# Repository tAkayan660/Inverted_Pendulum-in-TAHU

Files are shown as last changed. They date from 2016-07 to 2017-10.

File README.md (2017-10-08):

# Inverted_Pendulum-in-TAHU

## 機能
1. ロボット本体を倒立振子する
2. マイコンはArduino Megaを使用
3. 姿勢制御にIMU（MPU-6050）を使用



## 動画

倒立        https://youtu.be/ehn2ii576s0?t=45s

重心下げ    https://youtu.be/hFfJ6d6ZRYU

再生リスト　https://www.youtube.com/playlist?list=PLqcSOQa__YqBw24QBU1EO53jK8HO_nGts

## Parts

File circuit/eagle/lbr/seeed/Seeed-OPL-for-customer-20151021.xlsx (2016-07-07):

OPL list
Seeed SKU | MPN | Description | Category | Package | Manufacturer | Datasheet | Price（$）/pcs | Pieces/set | Solder points Qty | Assem.Cost/pcs（$） | Image URL | Distributor-URL
306010055 | FC-135 | SMD Crystal ABS07-32.768KHZ-7pF-20ppm-70K; | Crystal Oscillator | 2P-L3.2*W1.5mm | Xinhunjing | http://www.seeedstudio.com/wiki/images/7/78/306010055.pdf | 0.350 | 5 | 4 | 0.40 |  | http://www.seeedstudio.com/depot/OPLopen-parts-library-catalog-c-136_138/#306010055
306010005 | 49S | DIP Crystal 25MHz-20pF-20ppm;HC49US | Crystal Oscillator | HC49US | Xinhunjing | http://www.seeedstudio.com/wiki/images/5/5e/306010005.pdf | 0.150 | 10 | 2 | 0.20 |  | http://www.seeedstudio.com/depot/OPLopen-parts-library-catalog-c-136_138/#306010005
306010037 | 49S/18PF | DIP Crystal 16MHz-18pF-30ppm-50R; | Crystal Oscillator | HC49/US | Xinhunjing | http://www.seeedstudio.com/wiki/images/5/57/306010037.pdf | 0.150 | 10 | 2 | 0.20 |  | http://www.seeedstudio.com/depot/OPLopen-parts-library-catalog-c-136_138/#306010037
306010054 | X053201602002 | SMD 16MHz-8pF-20ppm-40R | Crystal Oscillator | 2P-SMD-5.0X3.2 | JINGPENGYUAN | http://www.seeedstudio.com/wiki/images/9/9f/0500290P1.pdf | 0.350 | 5 | 2 | 0.20 |  | http://www.seeedstudio.com/depot/OPLopen-parts-library-catalog-c-136_138/#0500290P1
306010047 | 5032/2P | SMD Crystal 12Mhz-20pF-20ppm-40R; | Crystal Oscillator | 2P-L5.0*W3.2mm | Xinhunjing | http://www.seeedstudio.com/wiki/images/c/c7/306010047.pdf | 0.450 | 5 | 2 | 0.20 |  | http://www.seeedstudio.com/depot/OPLopen-parts-library-catalog-c-136_138/#306010047
306010004 | 5032/4P | SMD Crystal 8MHz-20pF-20ppm; | Crystal Oscillator | 2P-L5.0*W3.2mm | Xinhunjing | http://www.seeedstudio.com/wiki/images/9/91/306010004.pdf | 0.450 | 5 | 2 | 0.20 |  | http://www.seeedstudio.com/depot/OPLopen-parts-library-catalog-c-136_138/#306010004
306010033 | 49S8M | DIP Crystal 8MHz-20pF-20ppm-60R; | Crystal Oscillator | HC49S | Xinhunjing | http://www.seeedstudio.com/wiki/images/c/ca/306010033.pdf | 0.150 | 10 | 2 | 0.20 |  | http://www.seeedstudio.com/depot/OPLopen-parts-library-catalog-c-136_138/#306010033
305030028 | 2N7002,215 | SMD MOSFET N-CH 60V-300mA Logic Level FET; | Transistor | SOT-23 | NXP | http://www.seeedstudio.com/wiki/images/c/c6/305030028.pdf | 0.050 | 30 | 3 | 0.30 |  | http://www.seeedstudio.com/depot/OPLopen-parts-library-catalog-c-136_138/#305030028
305030015 | CJ2302 | SMD MOSFET N-CH 20V 2.1A | Transistor | SOT23 | JCET | http://www.seeedstudio.com/wiki/images/e/e7/0440200P1.pdf | 0.100 | 10 | 3 | 0.30 |  | http://www.seeedstudio.com/depot/OPLopen-parts-library-catalog-c-136_138/#0440200P1
305030018 | Si2343CDS | SMD MOSFET P-CH 30V-5.9A | Transistor | SOT-23 | Vishay Siliconix |  | 0.700 | 5 | 3 | 0.30 |  | http://www.seeedstudio.com/depot/OPLopen-parts-library-catalog-c-136_138/#305030018
305030014 | CJ2305 | SMD MOSFET P-CH -8V -4.1A | Transistor | SOT-23 | JCET | http://www.seeedstudio.com/wiki/images/a/ac/0440210P1.pdf | 0.100 | 10 | 3 | 0.30 |  | http://www.seeedstudio.com/depot/OPLopen-parts-library-catalog-c-136_138/#0440210P1
305010018 | S9013 | SMD Transistors NPN 25V-500mA | Transistor | SOT-23 | JCET | http://www.seeedstudio.com/wiki/images/6/67/0400000P1.pdf | 0.040 | 50 | 3 | 0.30 |  | http://www.seeedstudio.com/depot/OPLopen-parts-library-catalog-c-136_138/#0400000P1
305020006 | S8550 | SMD Transistors PNP 25V-500mA | Transistor | SOT-23 |  | http://www.seeedstudio.com/wiki/images/e/e5/0410030P1.pdf | 0.040 | 50 | 3 | 0.30 |  | http://www.seeedstudio.com/depot/OPLopen-parts-library-catalog-c-136_138/#0410030P1
305010017 | S8050 | SMD Transistors NPN 25V-500mW; | Transistor | SOT-23 | JCET | http://www.seeedstudio.com/wiki/images/b/ba/305010017.pdf | 0.040 | 50 | 3 | 0.30 |  | http://www.seeedstudio.com/depot/OPLopen-parts-library-catalog-c-136_138/#305010017
305010022 | S9014J6 | SMD Transistor NPN 50V-100mA; | Transistor | SOT-23 | Changjiang | http://www.seeedstudio.com/wiki/images/2/2c/305010022.pdf | 0.050 | 30 | 3 | 0.30 |  | http://www.seeedstudio.com/depot/OPLopen-parts-library-catalog-c-136_138/#305010022
312010004 | KS-12065D03YA | DIP Buzzer 3V,30mA, 2700±300Hz | Audio product | 2P-7.6-D12*H6.5mm | Guangjixing | http://www.seeedstudio.com/wiki/images/c/cb/312020003.pdf | 0.500 | 5 | 2 | 0.20 |  | http://www.seeedstudio.com/depot/OPLopen-parts-library-catalog-c-136_138/#312010004
302020027 | TAJD477M006RNJ | SMD CAP Tantalum 470uF-6.3V;D | Capacitor | AVX-D | AVX |  | 0.500 | 5 | 2 | 0.20 |  | http://www.seeedstudio.com/depot/OPLopen-parts-library-catalog-c-136_138/#302020027
302030031 |  | DIP CAP Aluminum 100uF-16V | Capacitor | Radial-D5.0*H7.0mm | JWCO | http://www.seeedstudio.com/wiki/images/1/14/302030031.pdf | 0.030 | 50 | 2 | 0.20 |  | http://www.seeedstudio.com/depot/OPLopen-parts-library-catalog-c-136_138/#302030031
302020025 | TAJC107K010RNJ | SMD CAP Tantalum 100uF-10V 10% | Capacitor | AVX-C | AVX | http://www.seeedstudio.com/wiki/images/a/ae/0130170P1.pdf | 0.200 | 10 | 2 | 0.20 |  | http://www.seeedstudio.com/depot/OPLopen-parts-library-catalog-c-136_138/#0130170P1
302020022 | TAJC476K016RNJ | SMD CAP Tantalum 47uF-16V | Capacitor | AVX-C | AVX | http://www.seeedstudio.com/wiki/images/c/c7/302020022.pdf | 0.200 | 10 | 2 | 0.20 |  | http://www.seeedstudio.com/depot/OPLopen-parts-library-catalog-c-136_138/#302020022
302020020 | TAJB476K010RNJ | SMD CAP Tantalum 47uF-10V 10% | Capacitor | AVX-B | AVX | http://www.seeedstudio.com/wiki/images/f/fb/0130180P1.pdf | 0.200 | 10 | 2 | 0.20 |  | http://www.seeedstudio.com/depot/OPLopen-parts-library-catalog-c-136_138/#0130180P1
302020005 | TAJC476K006RNJ | SMD CAP Tantalum 47uF-6.3V | Capacitor | AVX-A | AVX |  | 0.150 | 20 | 2 | 0.20 |  | http://www.seeedstudio.com/depot/OPLopen-parts-library-catalog-c-136_138/#302020005
302020026 | TAJC226K025RNJ | SMD CAP Tantalum 22uF-25V 10% 2312 | Capacitor | AVX-C | AVX | http://www.seeedstudio.com/wiki/images/f/fd/0130360P1.pdf | 0.370 | 10 | 2 | 0.20 |  | http://www.seeedstudio.com/depot/OPLopen-parts-library-catalog-c-136_138/#0130360P1
302020021 | TAJB226K010RNJ | SMD CAP Tantalum 22uF-10V 10% | Capacitor | AVX-B | AVX | http://www.seeedstudio.com/wiki/images/8/82/0130240P1.pdf | 0.130 | 20 | 2 | 0.20 |  | http://www.seeedstudio.com/depot/OPLopen-parts-library-catalog-c-136_138/#0130240P1
302010171 | CC0805MKX5R5BB226 | SMD CAP Ceramic 22uF-6.3V-20%-X5R; | Capacitor | 0805 | YAGEO |  | 0.050 | 50 | 2 | 0.20 |  | http://www.seeedstudio.com/depot/OPLopen-parts-library-catalog-c-136_138/#302010171
302010181 | CC1206KKX5R8BB106 | SMD CAP Ceramic 10uF-25V-10%-X5R | Capacitor | 1206 | YAGEO |  | 0.130 | 20 | 2 | 0.20 |  | http://www.seeedstudio.com/depot/OPLopen-parts-library-catalog-c-136_138/#302010181
302010178 | CC0805KKX5R8BB106 | SMD CAP Ceramic 10uF-25V-10%-X5R | Capacitor | 0805 | YAGEO | http://www.seeedstudio.com/wiki/images/2/20/0100080P1.pdf | 0.050 | 50 | 2 | 0.20 |  | http://www.seeedstudio.com/depot/OPLopen-parts-library-catalog-c-136_138/#0100080P1
302020019 | TAJB106K016RNJ | SMD CAP Tantalum 10uF-16V 10% | Capacitor | AVX-B | AVX | http://www.seeedstudio.com/wiki/images/f/f6/0130120P1.pdf | 0.150 | 20 | 2 | 0.20 |  | http://www.seeedstudio.com/depot/OPLopen-parts-library-catalog-c-136_138/#0130120P1
302020002 | TAJA106K016RNJ | SMD CAP Tantalum 10uF-16V 10% | Capacitor | AVX-A | AVX | http://www.seeedstudio.com/wiki/images/1/1b/0130050P1.pdf | 0.130 | 20 | 2 | 0.20 |  | http://www.seeedstudio.com/depot/OPLopen-parts-library-catalog-c-136_138/#0130050P1
302020011 | TAJA106K010RNJ | SMD CAP Tantalum 10uF-10V 10% | Capacitor | AVX-A | AVX | http://www.seeedstudio.com/wiki/images/5/59/0130040P1.pdf (http://www.seeedstudio.com/wiki/images/0/0d/302010146.pdf) | 0.130 | 20 | 2 | 0.20 |  | http://www.seeedstudio.com/depot/OPLopen-parts-library-catalog-c-136_138/#0130040P1
302010243 | CC1206KKX5R9BB475 | SMD CAP Ceramic 4.7uF-50V-10%-X5R; | Capacitor | 1206 | YAGEO |  | 0.250 | 10 | 2 | 0.20 |  | http://www.seeedstudio.com/depot/OPLopen-parts-library-catalog-c-136_138/#302010243
302010146 | CC0805KKX5R8BB475 | SMD CAP Ceramic 4.7uF-25V-10%-X5R;0805 | Capacitor | C0805 | YAGEO | http://www.seeedstudio.com/wiki/images/0/0d/302010146.pdf | 0.040 | 50 | 2 | 0.20 |  | http://www.seeedstudio.com/depot/OPLopen-parts-library-catalog-c-136_138/#302010146
302010111 | CC0603KRX5R6BB475 | SMD CAP Ceramic 4.7uF-10V-10%-X5R; | Capacitor | 0603 | YAGEO |  | 0.040 | 50 | 2 | 0.20 |  | http://www.seeedstudio.com/depot/OPLopen-parts-library-catalog-c-136_138/#302010111
302010019 | CC0402MRX5R5BB475 | SMD CAP Ceramic 4.7uF-6.3V-20%-X5R | Capacitor | 0402 | YAGEO |  | 0.200 | 10 | 2 | 0.20 |  | http://www.seeedstudio.com/depot/OPLopen-parts-library-catalog-c-136_138/#302010019
302010148 | CC0805KKX7R8BB225 | SMD CAP Ceramic 2.2uF-25V-10%-X7R;0805 | Capacitor | C0805 | YAGEO | http://www.seeedstudio.com/wiki/images/a/ac/302010056.pdf | 0.050 | 50 | 2 | 0.20 |  | http://www.seeedstudio.com/depot/OPLopen-parts-library-catalog-c-136_138/#302010148
302010179 | CC0805KKX7R8BB105 | SMD CAP Ceramic 1uF-25V-10%-X7R | Capacitor | 0805 | YAGEO | http://www.seeedstudio.com/wiki/images/8/89/0100440P1.pdf (http://www.seeedstudio.com/wiki/images/a/ac/302010056.pdf) | 0.030 | 50 | 2 | 0.20 |  | http://www.seeedstudio.com/depot/OPLopen-parts-library-catalog-c-136_138/#0100440P1
302010139 | CC0603KRX7R8BB105 | SMD CAP Ceramic 1uF-25V-10%-X7R | Capacitor | 0603 | YAGEO | http://www.seeedstudio.com/wiki/images/a/af/0100340P1.pdf (http://www.seeedstudio.com/wiki/File:302010056.pdf) | 0.015 | 100 | 2 | 0.20 |  | http://www.seeedstudio.com/depot/OPLopen-parts-library-catalog-c-136_138/#0100340P1
302010040 | CC0402KRX5R6BB105 | SMD CAP Ceramic 1uF-10V-10%-X5R | Capacitor | 0402 | YAGEO |  | 0.015 | 100 | 2 | 0.20 |  | http://www.seeedstudio.com/depot/OPLopen-parts-library-catalog-c-136_138/#302010040
302010073 | CC0603KRX7R8BB224 | SMD CAP Ceramic 220nF-25V-10%-X7R;0603 | Capacitor | 0603 | YAGEO | http://www.seeedstudio.com/wiki/images/a/ac/302010056.pdf | 0.015 | 100 | 2 | 0.20 |  | http://www.seeedstudio.com/depot/OPLopen-parts-library-catalog-c-136_138/#302010073
302010165 | CC0805KRX7R9BB104 | SMD CAP Ceramic 100nF-50V-10%-X7R; | Capacitor | 0805 | YAGEO | http://www.seeedstudio.com/wiki/File:302010056.pdf (http://www.seeedstudio.com/wiki/images/a/ac/302010056.pdf) | 0.015 | 100 | 2 | 0.20 |  | http://www.seeedstudio.com/depot/OPLopen-parts-library-catalog-c-136_138/#302010165
302010138 | CC0603KRX7R9BB104 | SMD CAP Ceramic 100nF-50V-10%-X7R | Capacitor | 0603 | YAGEO | http://www.seeedstudio.com/wiki/images/3/35/0100020P1.pdf | 0.015 | 100 | 2 | 0.20 |  | http://www.seeedstudio.com/depot/OPLopen-parts-library-catalog-c-136_138/#0100020P1
302010024 | CC0402KRX7R8BB104 | SMD CAP Ceramic 100nF-25V-10%-X7R | Capacitor | 0402 | YAGEO | http://www.seeedstudio.com/wiki/images/a/ac/302010056.pdf | 0.015 | 100 | 2 | 0.20 |  | http://www.seeedstudio.com/depot/OPLopen-parts-library-catalog-c-136_138/#302010024
302010002 | CC0402KRX7R8BB473 | SMD CAP Ceramic 47nF-25V-10%-X7R; | Capacitor | 0402 | YAGEO |  | 0.010 | 100 | 2 | 0.20 |  | http://www.seeedstudio.com/depot/OPLopen-parts-library-catalog-c-136_138/#302010002
302010088 | CC0603KRX7R9BB333 | SMD CAP Ceramic 33nF-50V-10%-X7R;0603 | Capacitor | 0603 | YAGEO | http://www.seeedstudio.com/wiki/images/a/ac/302010056.pdf | 0.015 | 100 | 2 | 0.20 |  | http://www.seeedstudio.com/depot/OPLopen-parts-library-catalog-c-136_138/#302010088
302010095 | CC0603KRX7R9BB223 | SMD CAP Ceramic 22nF-50V-10%-X7R;0603 | Capacitor | C0603 | YAGEO | http://www.seeedstudio.com/wiki/images/a/ac/302010056.pdf | 0.010 | 100 | 2 | 0.20 |  | http://www.seeedstudio.com/depot/OPLopen-parts-library-catalog-c-136_138/#302010095
302010202 |  | DIP CAP Ceramic Disc 10nF-50V-Y5V | Capacitor | Radial-Disc-2.5-D4.0mm |  |  | 0.015 | 100 | 2 | 0.20 |  | http://www.seeedstudio.com/depot/OPLopen-parts-library-catalog-c-136_138/#302010202
302010140 | CC0603KRX7R9BB103 | SMD CAP Ceramic 10nF-50V-10%-X7R | Capacitor | 0603 | YAGEO | http://www.seeedstudio.com/wiki/images/e/eb/0100350P1.pdf (http://www.seeedstudio.com/wiki/images/f/f0/302010067.pdf%20302010094) | 0.010 | 100 | 2 | 0.20 |  | http://www.seeedstudio.com/depot/OPLopen-parts-library-catalog-c-136_138/#0100350P1
302010006 | CC0402KRX7R9BB103 | SMD CAP Ceramic 10nF-50V-10%-X7R | Capacitor | 0402 | YAGEO | http://www.seeedstudio.com/wiki/images/f/f0/302010067.pdf | 0.010 | 100 | 2 | 0.20 |  | http://www.seeedstudio.com/depot/OPLopen-parts-library-catalog-c-136_138/#302010006
302010144 | CC0603KRX7R9BB472 | SMD CAP Ceramic 4.7nF-50V-10%-X7R | Capacitor | 0603 | YAGEO | http://www.seeedstudio.com/wiki/images/f/fd/0130360P1.pdf | 0.010 | 100 | 2 | 0.20 |  | http://www.seeedstudio.com/depot/OPLopen-parts-library-catalog-c-136_138/#0100850P1
302010056 | CC0603KRX7R9BB222 | SMD CAP Ceramic 2.2nF-50V-10%-X7R | Capacitor | 0603 | YAGEO | http://www.seeedstudio.com/wiki/images/a/ac/302010056.pdf | 0.010 | 100 | 2 | 0.20 |  | http://www.seeedstudio.com/depot/OPLopen-parts-library-catalog-c-136_138/#302010056
302010141 | CC0603KRX7R9BB102 | SMD CAP Ceramic 1nF-50V-10%-X7R | Capacitor | 0603 | YAGEO | http://www.seeedstudio.com/wiki/images/c/cf/0100370P1.pdf | 0.010 | 100 | 2 | 0.20 |  | http://www.seeedstudio.com/depot/OPLopen-parts-library-catalog-c-136_138/#0100370P1
302010005 | CC0402KRX7R9BB102 | SMD CAP Ceramic 1nF-50V-10%-X7R; | Capacitor | 0402 | YAGEO |  | 0.050 | 50 | 2 | 0.20 |  | http://www.seeedstudio.com/depot/OPLopen-parts-library-catalog-c-136_138/#302010005
302010094 | CC0603JRNPO9BN221 | SMD CAP Ceramic 220pF-50V-5%-NPO; | Capacitor | C0603 | YAGEO | http://www.seeedstudio.com/wiki/images/f/f0/302010067.pdf 302010094 (http://www.seeedstudio.com/wiki/File:302010067.pdf) | 0.020 | 100 | 2 | 0.20 |  | http://www.seeedstudio.com/depot/OPLopen-parts-library-catalog-c-136_138/#302010094
302010013 | CC0402JRNPO9BN221 | SMD CAP Ceramic 220pF-50V-5%-NPO | Capacitor | 0402 | YAGEO | http://www.seeedstudio.com/wiki/images/f/f0/302010067.pdf | 0.030 | 50 | 2 | 0.20 |  | http://www.seeedstudio.com/depot/OPLopen-parts-library-catalog-c-136_138/#302010013
302010076 | CC0603JRNPO9BN101 | SMD CAP Ceramic 100pF-50V-5%-NPO;0603 | Capacitor | 0603 | YAGEO | http://www.seeedstudio.com/wiki/images/f/f0/302010067.pdf | 0.010 | 100 | 2 | 0.20 |  | http://www.seeedstudio.com/depot/OPLopen-parts-library-catalog-c-136_138/#302010076
302010126 | CC0603JRNPO9BN390 | SMD CAP Ceramic 39pF-50V-5%-NPO;0603 | Capacitor | C0603 | YAGEO | http://www.seeedstudio.com/wiki/images/f/f0/302010067.pdf (http://www.seeedstudio.com/wiki/images/0/03/0100230P1.pdf) | 0.010 | 100 | 2 | 0.20 |  | http://www.seeedstudio.com/depot/OPLopen-parts-library-catalog-c-136_138/#302010126
302010150 | CC0805JRNPO9BN270 | SMD CAP Ceramic 27pF-50V-5%-NPO | Capacitor | 0805 | YAGEO | http://www.seeedstudio.com/wiki/images/b/be/320020004.png | 0.030 | 50 | 2 | 0.20 |  | http://www.seeedstudio.com/depot/OPLopen-parts-library-catalog-c-136_138/#302010150
302010142 | CC0603JRNPO9BN270 | SMD CAP Ceramic 27pF-50V-5%-NPO | Capacitor | 0603 | YAGEO | http://www.seeedstudio.com/wiki/images/0/01/0100410P1.pdf (http://www.seeedstudio.com/wiki/images/b/be/320020004.png) | 0.010 | 100 | 2 | 0.20 |  | http://www.seeedstudio.com/depot/OPLopen-parts-library-catalog-c-136_138/#0100410P1
302010027 | CC0402JRNPO9BN270 | SMD CAP Ceramic 27pF-50V-5%-NPO | Capacitor | 0402 | YAGEO | http://www.seeedstudio.com/wiki/images/b/be/320020004.png | 0.010 | 100 | 2 | 0.20 |  | http://www.seeedstudio.com/depot/OPLopen-parts-library-catalog-c-136_138/#302010027
302010143 | CC0603JRNPO9BN220 | SMD CAP Ceramic 22pF-50V-5%-NPO | Capacitor | 0603 | YAGEO | http://www.seeedstudio.com/wiki/images/7/73/0100620P1.pdf | 0.010 | 100 | 2 | 0.20 |  | http://www.seeedstudio.com/depot/OPLopen-parts-library-catalog-c-136_138/#0100620P1
302010018 | CC0402JRNPO9BN220 | SMD CAP Ceramic 22pF-50V-5%-NPO | Capacitor | 0402 | YAGEO | http://www.seeedstudio.com/wiki/File:302010067.pdf (http://www.seeedstudio.com/wiki/images/b/be/320020004.png) | 0.010 | 100 | 2 | 0.20 |  | http://www.seeedstudio.com/depot/OPLopen-parts-library-catalog-c-136_138/#302010018
302010162 | CC0805JRNPO9BN180 | SMD CAP Ceramic 18pF-50V-5%-NPO | Capacitor | 0805 | YAGEO |  | 0.010 | 100 | 2 | 0.20 |  | http://www.seeedstudio.com/depot/OPLopen-parts-library-catalog-c-136_138/#302010162
302010016 | CC0402JRNPO9BN180 | SMD CAP Ceramic 18pF-50V-5%-NPO | Capacitor | 0402 | YAGEO |  | 0.010 | 100 | 2 | 0.20 |  | http://www.seeedstudio.com/depot/OPLopen-parts-library-catalog-c-136_138/#302010016
302010083 | CC0603JRNPO9BN180 | SMD CAP Ceramic 18pF-50V-5%-NPO; | Capacitor | 0603 | YAGEO | http://www.seeedstudio.com/wiki/images/7/77/320020027.png | 0.010 | 100 | 2 | 0.20 |  | http://www.seeedstudio.com/depot/OPLopen-parts-library-catalog-c-136_138/#302010083
302010082 | CC0603JRNPO9BN150 | SMD CAP Ceramic 15pF-50V-5%-NPO;0603 | Capacitor | 0603 | YAGEO | http://www.seeedstudio.com/wiki/images/f/f0/302010067.pdf (http://www.seeedstudio.com/wiki/images/e/ef/320020003.png) | 0.010 | 100 | 2 | 0.20 |  | http://www.seeedstudio.com/depot/OPLopen-parts-library-catalog-c-136_138/#302010082
302010067 | CC0603JRNPO9BN120 | SMD CAP Ceramic 12pF-50V-5%-NP0 | Capacitor | 0603 | YAGEO | http://www.seeedstudio.com/wiki/images/f/f0/302010067.pdf | 0.010 | 100 | 2 | 0.20 |  | http://www.seeedstudio.com/depot/OPLopen-parts-library-catalog-c-136_138/#302010067
302010097 | CC0603JRNPO9BN100 | SMD CAP Ceramic 10pF-50V-5%-NPO | Capacitor | 0603 | YAGEO | http://www.seeedstudio.com/wiki/images/b/be/320020004.png | 0.010 | 100 | 2 | 0.20 |  | http://www.seeedstudio.com/depot/OPLopen-parts-library-catalog-c-136_138/#302010097
302010001 | CC0402JRNPO9BN100 | SMD CAP Ceramic 10pF-50V-5%-NPO | Capacitor | 0402 | YAGEO |  | 0.010 | 100 | 2 | 0.20 |  | http://www.seeedstudio.com/depot/OPLopen-parts-library-catalog-c-136_138/#302010001
302010223 | CC0402CRNPO9BN2R2 | SMD CAP Ceramic 2.2pF-50V-0.25PF-NPO | Capacitor | 0402 | YAGEO | http://www.seeedstudio.com/wiki/images/b/be/320020004.png | 0.010 | 100 | 2 | 0.20 |  | http://www.seeedstudio.com/depot/OPLopen-parts-library-catalog-c-136_138/#302010223
302010102 | CC0603CRNPO9BN2R2 | SMD CAP Ceramic 2.2pF-50V-0.25pF-NPO | Capacitor | 0603 | YAGEO |  | 0.010 | 100 | 2 | 0.20 |  | http://www.seeedstudio.com/depot/OPLopen-parts-library-catalog-c-136_138/#302010102
302010046 | GRM1555C1H1R8BA01D | SMD CAP Ceramic 1.8pF-50V-0.1pF-NPO | Capacitor | 0402 | Murata |  | 0.010 | 100 | 2 | 0.20 |  | http://www.seeedstudio.com/depot/OPLopen-parts-library-catalog-c-136_138/#302010046
320020037 | P125-1102A0BS116A3 | DIP White Male Header VERT; | Connector | 1*2P-2.54-2.54-11.6/3.0mm | YXCON | http://www.seeedstudio.com/wiki/images/b/be/320020004.png (http://www.seeedstudio.com/wiki/images/c/cb/320020019.png) | 0.100 | 20 | 2 | 0.20 |  | http://www.seeedstudio.com/depot/OPLopen-parts-library-catalog-c-136_138/#320020037
320020015 | P125-1102A0BS116A2 | DIP Blue Male Header VERT | Connector | 1*2P-2.54-2.54-11.6/3.0mm | YXCON | http://www.seeedstudio.com/wiki/images/b/be/320020004.png | 0.100 | 20 | 2 | 0.20 |  | http://www.seeedstudio.com/depot/OPLopen-parts-library-catalog-c-136_138/#320020015
320020016 | P125-1102A0BS116A1 | DIP Black Male Header VERT | Connector | 1*2P-2.54-2.54-11.6/3.0mm | YXCON | http://www.seeedstudio.com/wiki/images/b/be/320020004.png | 0.100 | 20 | 2 | 0.20 |  | http://www.seeedstudio.com/depot/OPLopen-parts-library-catalog-c-136_138/#320020016
320020079 |  | DIP-Black-Male-Header-VERT-3P | Connector | 1X3P-2.54-2.54-11.6/3.0 | YXCON | http://www.seeedstudio.com/wiki/images/0/02/3460810P1.pdf (http://www.seeedstudio.com/wiki/images/b/be/320020004.png) | 0.100 | 20 | 3 | 0.30 |  | http://www.seeedstudio.com/depot/OPLopen-parts-library-catalog-c-136_138/#3460810P1
320020038 | P125-1103A0BS116A1 | DIP White Male Header VERT; | Connector | 1*3P-2.54-2.54-11.6/3.0mm | YXCON | http://www.seeedstudio.com/wiki/images/b/be/320020004.png | 0.120 | 20 | 3 | 0.30 |  | http://www.seeedstudio.com/depot/OPLopen-parts-library-catalog-c-136_138/#320020038
320020061 | P125-1103A0BR138A1 | DIP Black Male Header R/A; | Connector | 1*3P-2.54-2.54-6.0mm-90D-1 | YXCON |  | 0.120 | 20 | 3 | 0.30 |  | http://www.seeedstudio.com/depot/OPLopen-parts-library-catalog-c-136_138/#320020061
320020077 | P125-12A1BS116A1 | DIP Black Male Header | Connector | 2X3P-2.54-2.54-11.6/3.0 | YXCON | http://www.seeedstudio.com/wiki/images/7/72/3460180P1.pdf (http://www.seeedstudio.com/wiki/images/8/8b/320020018.png) | 0.060 | 20 | 6 | 0.60 |  | http://www.seeedstudio.com/depot/OPLopen-parts-library-catalog-c-136_138/#3460180P1
320020027 | P125-1203A0BS116A2 | DIP Yellow Male Header VERT; | Connector | 2*3P-2.54-2.54-11.6/3.0mm | YXCON | http://www.seeedstudio.com/wiki/images/7/77/320020027.png | 0.100 | 20 | 6 | 0.60 |  | http://www.seeedstudio.com/depot/OPLopen-parts-library-catalog-c-136_138/#320020027
320020003 | P125-1203A0BS116A1 | DIP Blue Male Header VERT; | Connector | 2*3P-2.54-2.54-11.6/3.0mm | YXCON | http://www.seeedstudio.com/wiki/images/e/ef/320020003.png (http://www.seeedstudio.com/wiki/images/2/25/320020010.pdf) | 0.150 | 20 | 6 | 0.60 |  | http://www.seeedstudio.com/depot/OPLopen-parts-library-catalog-c-136_138/#320020003
320020017 | P125-1104A0BS116A1 | DIP Black Male Header VERT | Connector | 1*4P-2.54-2.54-11.6/3.0mm | YXCON | http://www.seeedstudio.com/wiki/images/f/fb/320020089.png | 0.100 | 20 | 4 | 0.40 |  | http://www.seeedstudio.com/depot/OPLopen-parts-library-catalog-c-136_138/#320020017
320020005 | P125-1106A0BS116A1 | DIP Blue Male Header VERT | Connector | 1*6P-2.54-2.54-11.6/3.0mm | YXCON | http://www.seeedstudio.com/wiki/images/b/be/320020004.png | 0.100 | 20 | 6 | 0.60 |  | http://www.seeedstudio.com/depot/OPLopen-parts-library-catalog-c-136_138/#320020005
320020078 | P125-1106A1BS116A1 | DIP Black Male Header | Connector | 1X6P-2.54-2.54-11.6/3.0mm | YXCON | http://www.seeedstudio.com/wiki/images/2/2d/3460650P1.pdf | 0.100 | 20 | 6 | 0.60 |  | http://www.seeedstudio.com/depot/OPLopen-parts-library-catalog-c-136_138/#3460650P1
320020022 | P125-1106A0BS116A2 | DIP White Male Header VERT; | Connector | 1*6P-2.54-2.54-11.6/3.0mm | YXCON | http://www.seeedstudio.com/wiki/images/b/be/320020004.png (http://www.seeedstudio.com/wiki/images/0/0d/320030039.pdf) | 0.100 | 20 | 6 | 0.60 |  | http://www.seeedstudio.com/depot/OPLopen-parts-library-catalog-c-136_138/#320020022
320020024 | P125-1106B0BA2 | SMD Blue Male Header R/A; | Connector | 1*6P-2.54-2.54-9.3/6.0mm-2 | YXCON | http://www.seeedstudio.com/wiki/images/e/ef/320120007.pdf | 0.100 | 20 | 6 | 0.60 |  | http://www.seeedstudio.com/depot/OPLopen-parts-library-catalog-c-136_138/#320020024
320020031 | P125-1106B0BA1 | SMD Black Male Header R/A; | Connector | 1*6P-2.54-2.54-9.3/6.0mm-2 | YXCON | http://www.seeedstudio.com/wiki/images/d/d3/320030100.png | 0.100 | 20 | 6 | 0.60 |  | http://www.seeedstudio.com/depot/OPLopen-parts-library-catalog-c-136_138/#320020031
320020019 | P125-1106A0BR138A1 | DIP Black Short Male Header R/A; | Connector | 1X6P-2.54-2.54-6.0mm-90D-1 | YXCON | http://www.seeedstudio.com/wiki/images/c/cb/320020019.png (http://www.seeedstudio.com/wiki/images/a/a7/320030035.png) | 0.100 | 20 | 6 | 0.60 |  | http://www.seeedstudio.com/depot/OPLopen-parts-library-catalog-c-136_138/#320020019
320020070 | P125-1106A0BR138A2 | DIP Black Male Header R/A; | Connector | 1*6P-2.54-2.54-6.0mm-90D-2 | YXCON | http://www.seeedstudio.com/wiki/images/1/11/320030011.png | 0.100 | 20 | 6 | 0.60 |  | http://www.seeedstudio.com/depot/OPLopen-parts-library-catalog-c-136_138/#320020070
320020004 | P125-1108A0BS116A1 | DIP Blue Male Header VERT | Connector | 1*8P-2.54-2.54-11.6/3.0mm | YXCON | http://www.seeedstudio.com/wiki/images/b/be/320020004.png (http://www.seeedstudio.com/wiki/images/0/0d/320030039.pdf) | 0.100 | 20 | 8 | 0.80 |  | http://www.seeedstudio.com/depot/OPLopen-parts-library-catalog-c-136_138/#320020004
320020021 | P125-1108A0BS116A2 | DIP White Male Header VERT; | Connector | 1*8P-2.54-2.54-11.6/3.0mm | YXCON | http://www.seeedstudio.com/wiki/images/b/be/320020004.png | 0.100 | 20 | 8 | 0.80 |  | http://www.seeedstudio.com/depot/OPLopen-parts-library-catalog-c-136_138/#320020021
320020080 | P125-1108A1BS116A1 | DIP-Black-Male-Header-VERT-8P | Connector | 1X8P-2.54-2.54-11.6/3.0 | YXCON | http://www.seeedstudio.com/wiki/images/b/b5/3461050P1.pdf (http://www.seeedstudio.com/wiki/images/0/0d/320030039.pdf) | 0.100 | 20 | 8 | 0.80 |  | http://www.seeedstudio.com/depot/OPLopen-parts-library-catalog-c-136_138/#3461050P1
320020023 | P125-1108B0BA2 | SMD Blue Male Header R/A; | Connector | 1*8P-2.54-2.54-9.3/6.0mm-2 | YXCON | http://www.seeedstudio.com/wiki/images/0/0d/320030039.pdf | 0.120 | 20 | 8 | 0.80 |  | http://www.seeedstudio.com/depot/OPLopen-parts-library-catalog-c-136_138/#320020023
320020018 | P220-1110A0BS087A1 | DIP White Male Header VERT; | Connector | 1*10P-2.0-2.0-8.7/2.8mm | YXCON | http://www.seeedstudio.com/wiki/images/8/8b/320020018.png (http://www.seeedstudio.com/wiki/images/0/0d/320030039.pdf) | 0.200 | 10 | 10 | 1.00 |  | http://www.seeedstudio.com/depot/OPLopen-parts-library-catalog-c-136_138/#320020018
320020074 | P125-1110A0BR138A1 | DIP Black Male Header R/A; | Connector | 1*10P-2.54-2.54-6.0mm-90D-1 | YXCON | http://www.seeedstudio.com/wiki/images/e/e3/3460540P1.pdf | 0.120 | 20 | 10 | 1.00 |  | http://www.seeedstudio.com/depot/OPLopen-parts-library-catalog-c-136_138/#320020074
320020010 |  | DIP Black Male Header VERT; | Connector | 1*40P-2.54-2.54-11.6/3.0mm | YXCON | http://www.seeedstudio.com/wiki/images/2/25/320020010.pdf | 0.200 | 5 | 40 | 4.00 |  | http://www.seeedstudio.com/depot/OPLopen-parts-library-catalog-c-136_138/#320020010
320020089 | P220-1140A0BS087A1 | DIP White Male Header VERT; | Connector | 1*40P-2.0-2.0-8.7-2.8mm | YXCON | http://www.seeedstudio.com/wiki/images/f/fb/320020089.png | 0.250 | 5 | 40 | 4.00 |  | http://www.seeedstudio.com/depot/OPLopen-parts-library-catalog-c-136_138/#320020089
320020032 | P125-1140B0BA1 | SMD Black Male Header R/A; | Connector | 1*40P-2.0-2.0-4.0mm-2 | YXCON | http://www.seeedstudio.com/wiki/images/8/87/320030014.png | 0.400 | 5 | 40 | 4.00 |  | http://www.seeedstudio.com/depot/OPLopen-parts-library-catalog-c-136_138/#320020032
320020013 | P125-1140A0BR138A2 | DIP Black Short Male Header R/A; | Connector | 1*40P-2.54-2.54-6.0mm-90D-1 | YXCON |  | 0.400 | 5 | 40 | 4.00 |  | http://www.seeedstudio.com/depot/OPLopen-parts-library-catalog-c-136_138/#320020013
320030023 | F185-1102A1BSYA1 | DIP Black Female Header VERT; | Connector | 1*2P-2.54-8.5mm | YXCON | http://www.seeedstudio.com/wiki/images/0/0d/320030039.pdf | 0.150 | 10 | 2 | 0.20 |  | http://www.seeedstudio.com/depot/OPLopen-parts-library-catalog-c-136_138/#320030023
320120007 | GSL009-5.0-02P-12 | DIP Female Blue; | Connector | 2P-5.0 | SENGER | http://www.seeedstudio.com/wiki/images/e/ef/320120007.pdf (http://www.seeedstudio.com/wiki/images/0/0d/320030039.pdf) | 0.500 | 10 | 2 | 0.20 |  | http://www.seeedstudio.com/depot/OPLopen-parts-library-catalog-c-136_138/#320120007
320030100 | F185-1103A1BRYA1 | DIP Black Female Header; | Connector | 1*3P-2.54-8.5-90D | YXCON | http://www.seeedstudio.com/wiki/images/d/d3/320030100.png | 0.100 | 20 | 3 | 0.30 |  | http://www.seeedstudio.com/depot/OPLopen-parts-library-catalog-c-136_138/#320030100
320030035 | F185-1203A1BMYA1 | SMD Blue Female Header VERT | Connector | 2*3P-2.54-8.5mm | YXCON | http://www.seeedstudio.com/wiki/images/a/a7/320030035.png | 0.270 | 10 | 6 | 0.60 |  | http://www.seeedstudio.com/depot/OPLopen-parts-library-catalog-c-136_138/#320030035
320030011 | F185-1203A1BSYA1 | DIP Black Female Header VERT | Connector | 2*3P-2.54-8.5mm | YXCON | http://www.seeedstudio.com/wiki/images/1/11/320030011.png (http://www.seeedstudio.com/wiki/images/2/2d/320030013.png) | 0.200 | 10 | 6 | 0.60 |  | http://www.seeedstudio.com/depot/OPLopen-parts-library-catalog-c-136_138/#320030011
320030017 | F185-1104A1BSYA1 | DIP Black Female Header VERT | Connector | 1*4P-2.54-8.5mm | YXCON | http://www.seeedstudio.com/wiki/images/0/0d/320030039.pdf (http://www.seeedstudio.com/wiki/images/c/c9/320030076.png) | 0.150 | 10 | 4 | 0.40 |  | http://www.seeedstudio.com/depot/OPLopen-parts-library-catalog-c-136_138/#320030017
320030066 |  | DIP Long Blue Female Header | Connector | 2X3P-2.54-8.5+1.5-12.3 | YXCON | http://www.seeedstudio.com/wiki/images/0/01/3461240P1.pdf (http://www.seeedstudio.com/wiki/images/7/70/320030001.pdf) | 0.250 | 10 | 6 | 0.60 |  | http://www.seeedstudio.com/depot/OPLopen-parts-library-catalog-c-136_138/#3461240P1
320030019 | F185-1106A1BSYA3 | DIP Yellow Female Header VERT; | Connector | 1*6P-2.54-8.5mm | YXCON | http://www.seeedstudio.com/wiki/images/0/0d/320030039.pdf | 0.200 | 10 | 6 | 0.60 |  | http://www.seeedstudio.com/depot/OPLopen-parts-library-catalog-c-136_138/#320030019
320030012 | F185-1106A1BSYA2 | DIP Long Black Female Header VERT | Connector | 1*6P-2.54-8.5mm | YXCON | http://www.seeedstudio.com/wiki/images/0/0d/320030039.pdf (http://www.seeedstudio.com/wiki/images/f/f2/3460170P1.pdf) | 0.250 | 10 | 6 | 0.60 |  | http://www.seeedstudio.com/depot/OPLopen-parts-library-catalog-c-136_138/#320030012
320030004 | F185-1106A1BSYA1 | DIP Blue Female Header VERT | Connector | 1*6P-2.54-8.5mm | YXCON | http://www.seeedstudio.com/wiki/images/0/0d/320030039.pdf (http://www.seeedstudio.com/wiki/images/c/c5/320030020.png) | 0.200 | 10 | 6 | 0.60 |  | http://www.seeedstudio.com/depot/OPLopen-parts-library-catalog-c-136_138/#320030004
320030063 | F185-1106A1BSYA4 | DIP White Female Header | Connector | 1X6P-2.54-8.5 | YXCON | http://www.seeedstudio.com/wiki/images/e/e3/3460540P1.pdf | 0.200 | 10 | 6 | 0.60 |  | http://www.seeedstudio.com/depot/OPLopen-parts-library-catalog-c-136_138/#3460540P1
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

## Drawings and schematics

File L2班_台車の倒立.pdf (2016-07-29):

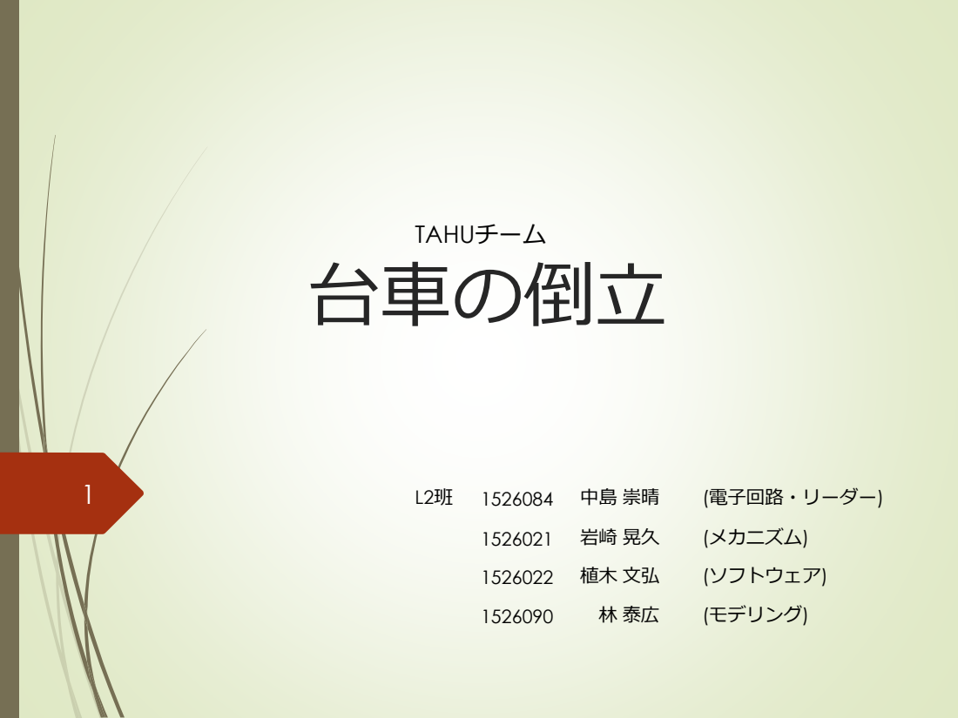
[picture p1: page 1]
台車の倒立; (電子回路・リーダー); (メカニズム); (ソフトウェア); (モデリング); TAHUチーム

目次

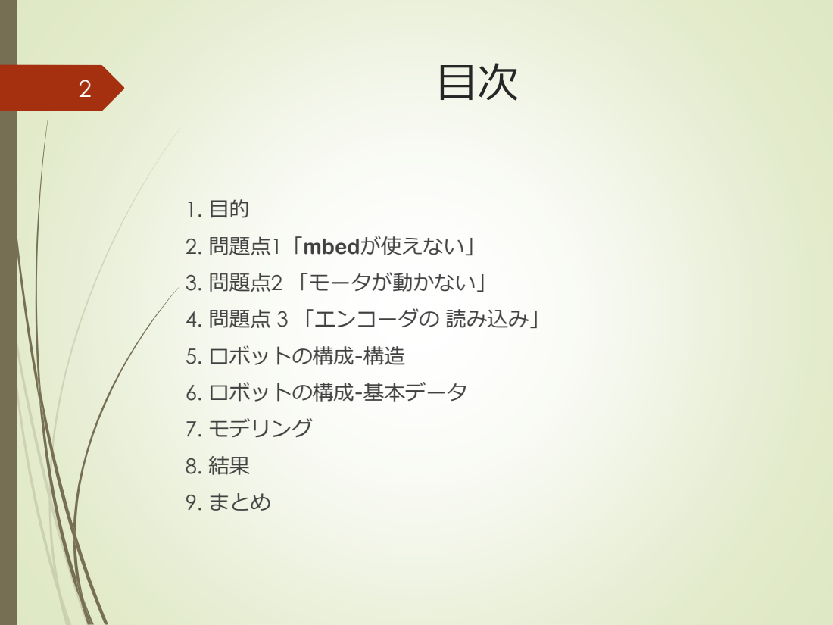
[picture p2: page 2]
2. 問題点1「mbedが使えない」; 3. 問題点2 「モータが動かない」; 4. 問題点 3 「エンコーダの 読み込み」; 5. ロボットの構成-構造; 6. ロボットの構成-基本データ; 7. モデリング; 9. まとめ

1. 目的

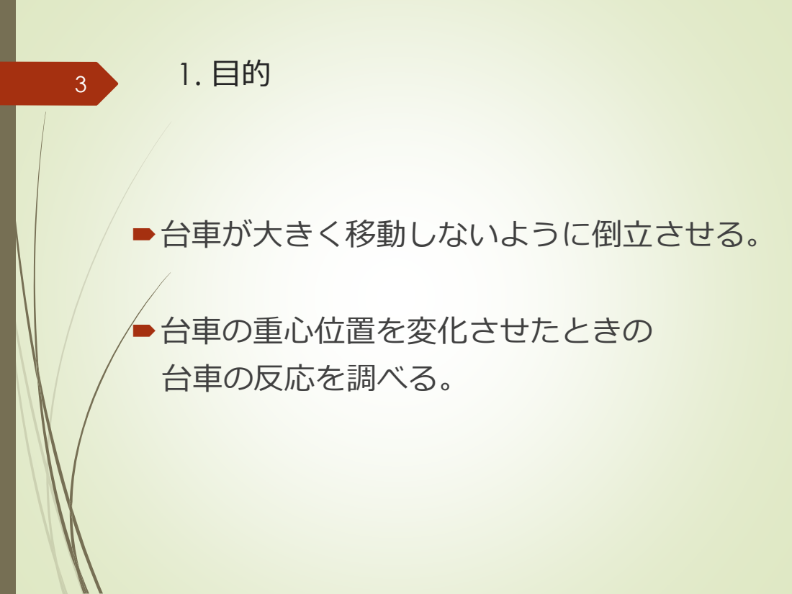
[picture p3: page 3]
台車が大きく移動しないように倒立させる。; 台車の重心位置を変化させたときの; 台車の反応を調べる。

## 2. 問題点１ 「mbedが使用できない。」

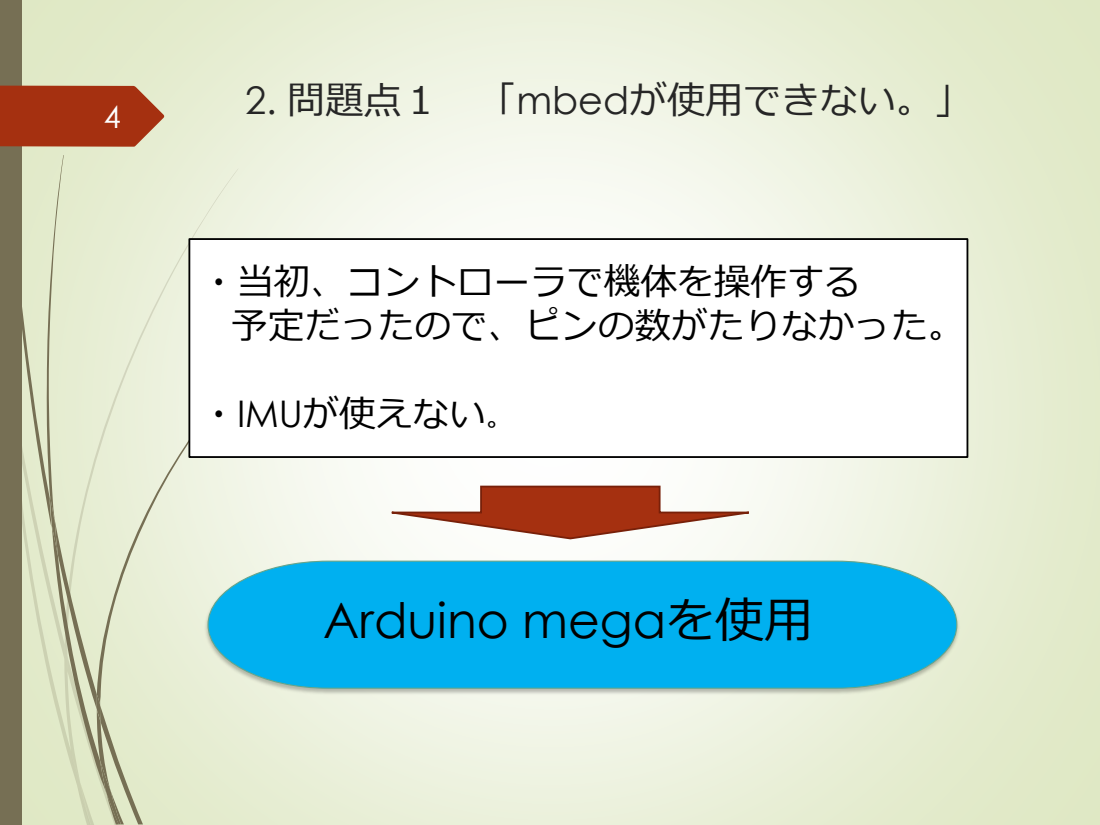
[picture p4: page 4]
Arduino megaを使用; ・当初、コントローラで機体を操作する 予定だったので、ピンの数がたりなかった。; ・IMUが使えない。

## 5 3. 問題点２ 「モータが動かない」

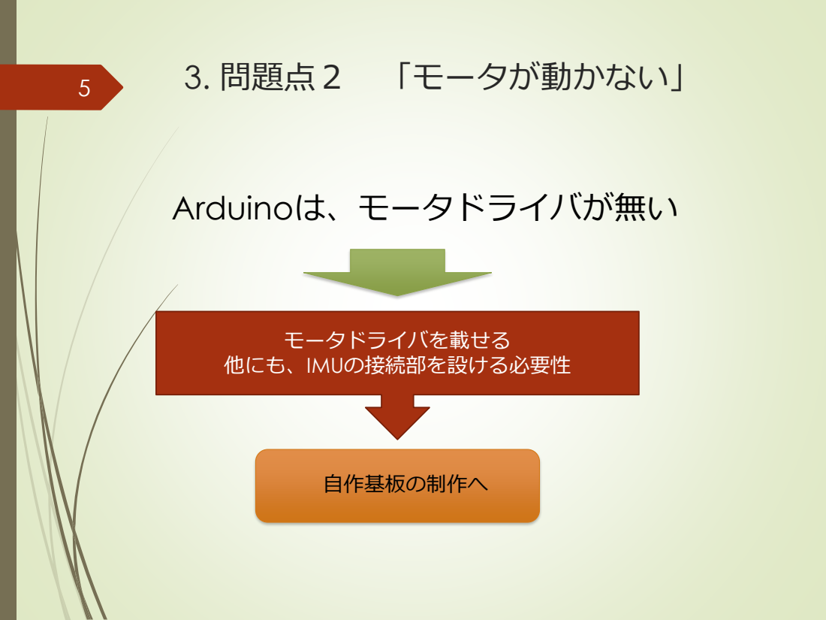
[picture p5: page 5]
Arduinoは、モータドライバが無い; モータドライバを載せる 他にも、IMUの接続部を設ける必要性; 自作基板の制作へ

## 3. 問題点２ 「モータが動かない」

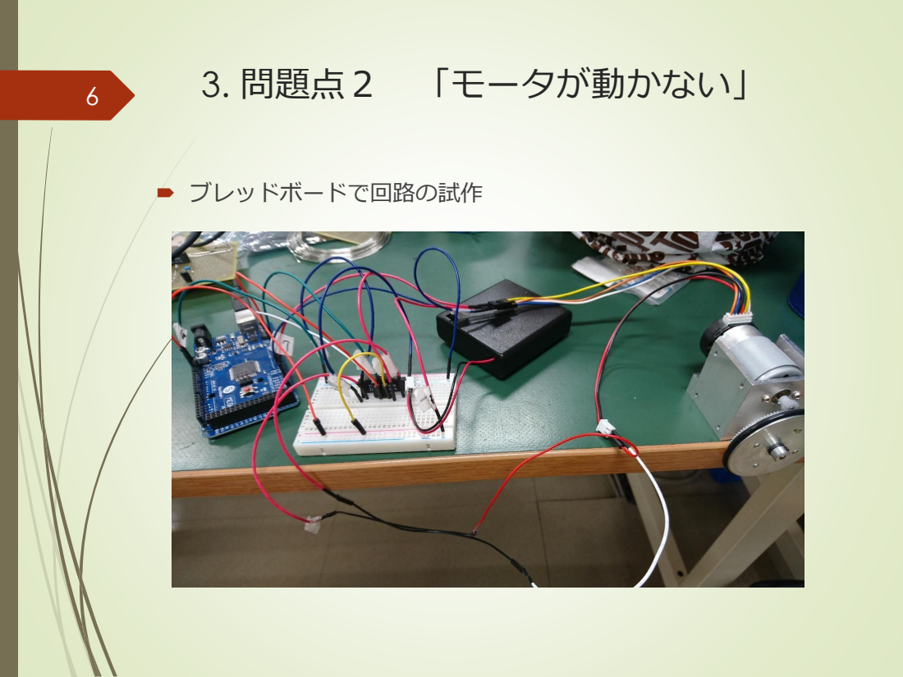
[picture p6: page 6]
ブレッドボードで回路の試作

## 7 3. 問題点２ 「モータが動かない」

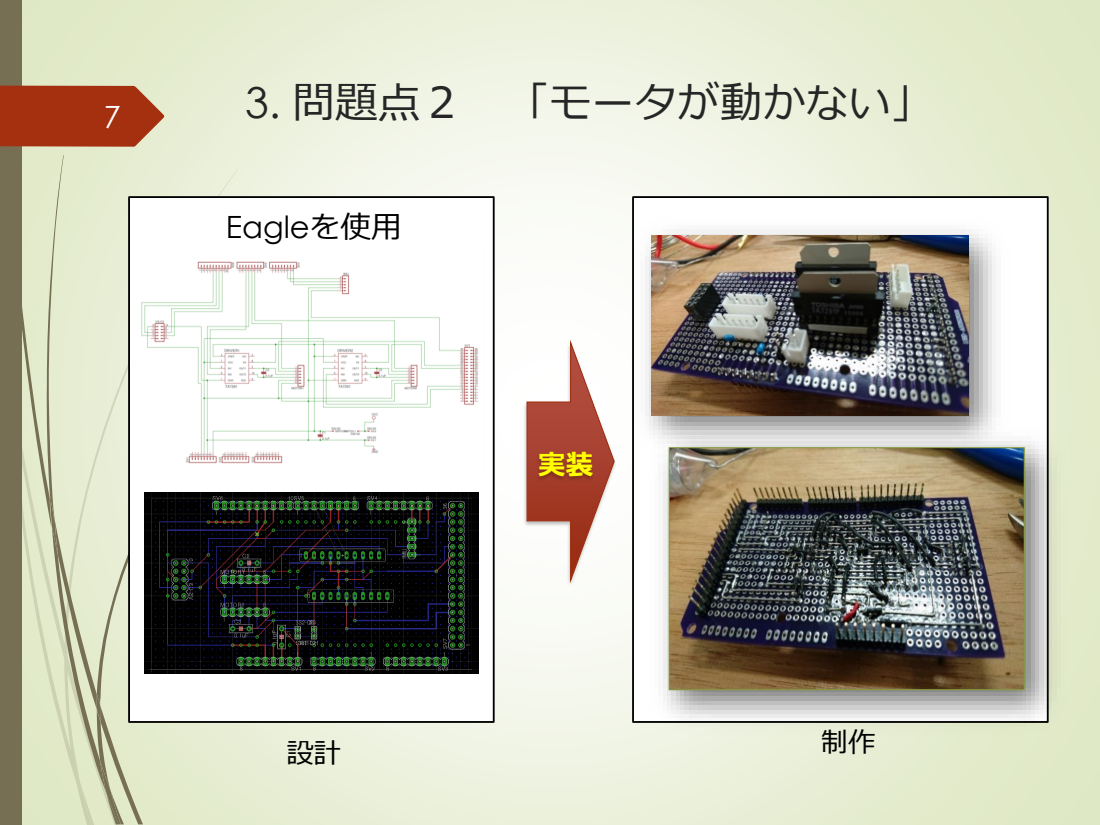
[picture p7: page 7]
Eagleを使用

## 3. 問題点２ 「モータが動かない」

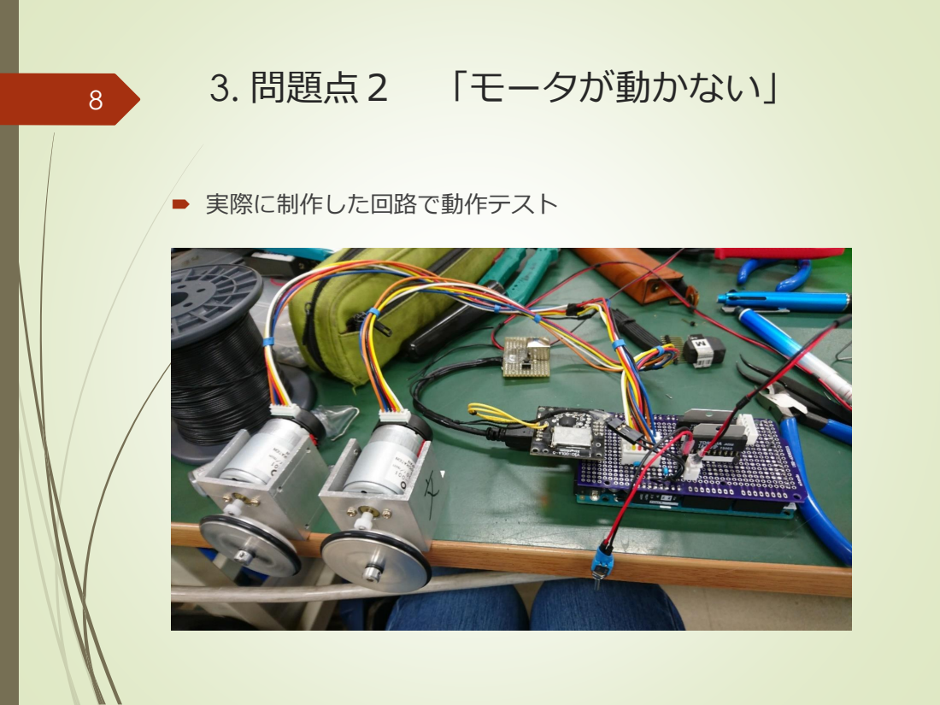
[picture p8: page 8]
実際に制作した回路で動作テスト

9 | 4. 問題点3 「エンコーダの読み込み」

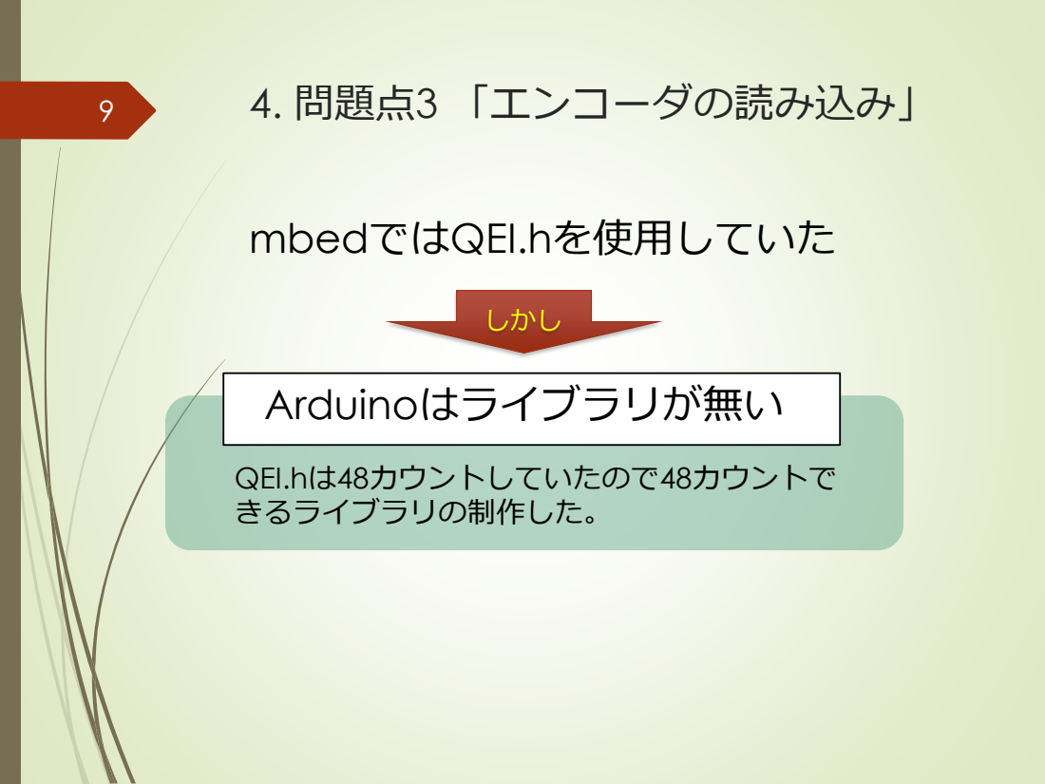
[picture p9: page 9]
mbedではQEI.hを使用していた; しかし; Arduinoはライブラリが無い; QEI.hは48カウントしていたので48カウントで きるライブラリの制作した。

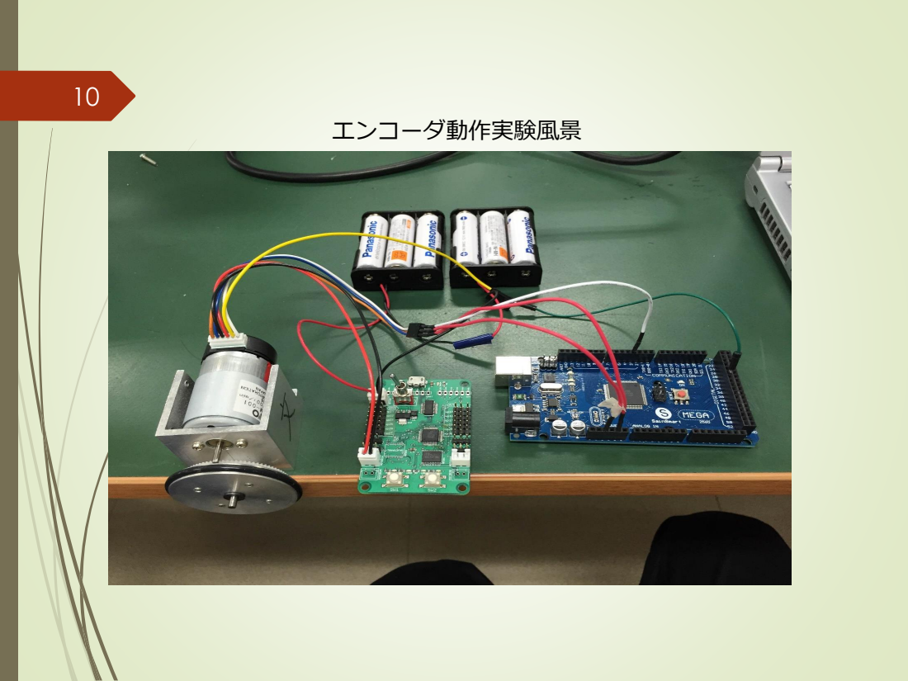
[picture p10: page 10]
エンコーダ; 動作実験風景

## 11 4. 問題点3 「エンコーダの読み込み」 結果

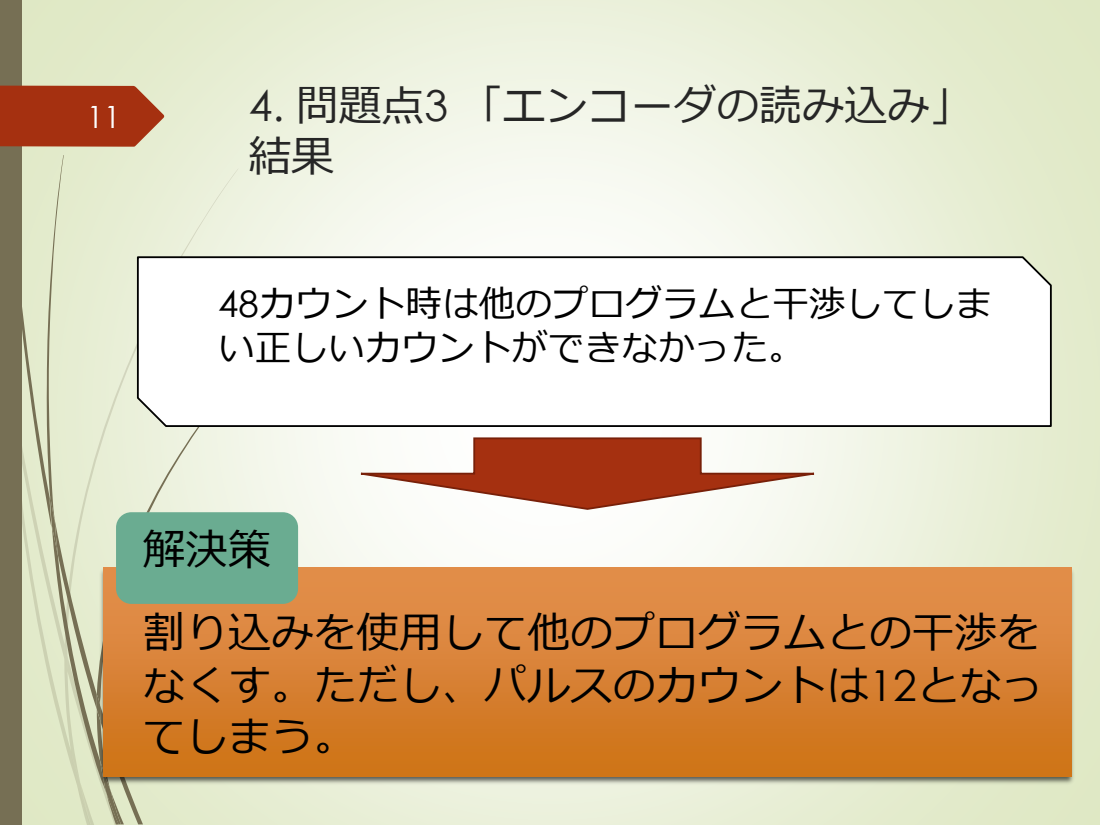
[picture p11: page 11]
割り込みを使用して他のプログラムとの干渉を なくす。ただし、パルスのカウントは12となっ てしまう。; 解決策; 48カウント時は他のプログラムと干渉してしま い正しいカウントができなかった。

12 | 4. 問題点3 「エンコーダの読み込み」 結果

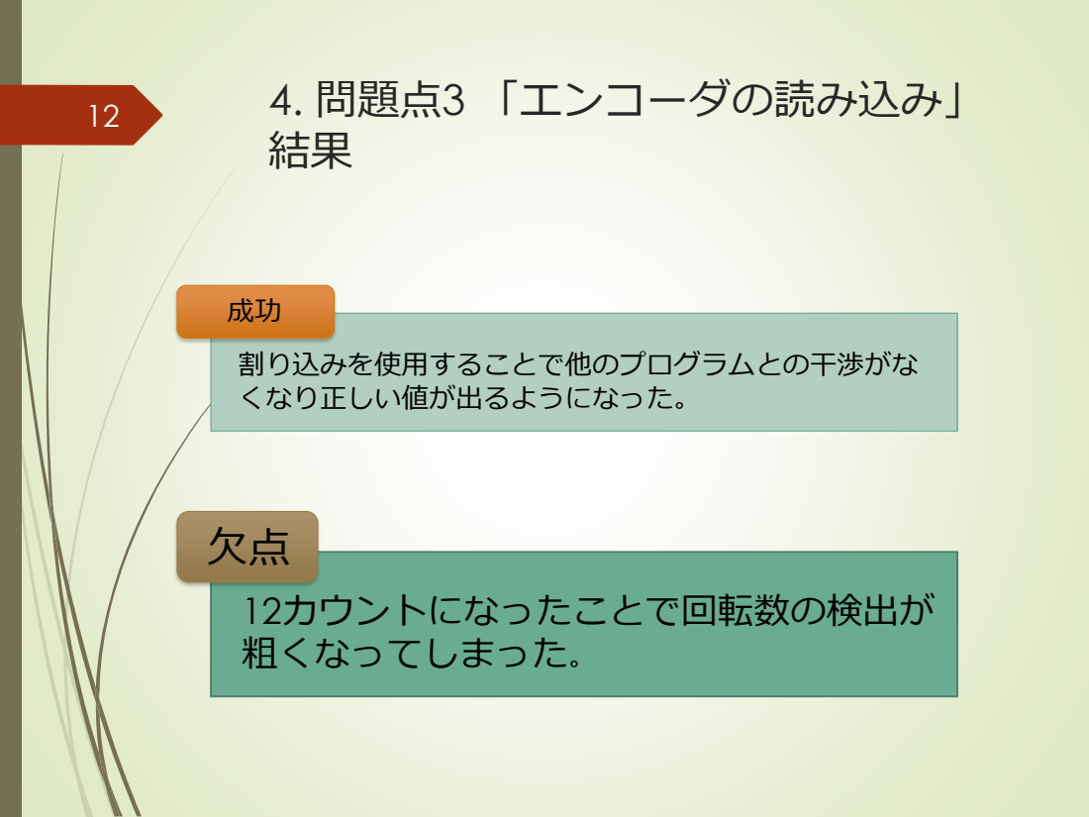
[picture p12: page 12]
12カウントになったことで回転数の検出が 粗くなってしまった。; 割り込みを使用することで他のプログラムとの干渉がな くなり正しい値が出るようになった。

## 5. ロボットの構成-構造

・最大の特徴「重心位置の変更できる」; 図：機体内部の写真; →電池ボックス・マイコンの高さ４段階に 分けて変更できる（本棚のように）; ←具体例 電池ボックスの位置をずらして 重心位置を変更; その他 「配線をなるべく機体内部に」 「ネジの種類の統一」

14 | 6. ロボットの構成-基本データ

・基本データ; ・使用既製品パーツ

項目 | 数値
サイズ | L89×W153×H382[mm]
総重量 | 1.43[kg]
電源電圧 | 9.6[v]

仕様 | パーツ名(又は型番) | 参考
マイコン | Arduino Mega
モータ | DMN29BM-001 | エンコーダ付きモータ 定格12[v]
モータドライバ | TOSHIBA TA7291P
スイッチ | トグルスイッチ | 主電源用

プッシュスイッチ | コントローラーリセット用
タクトスイッチ | Arduinoリセット用

IMU | GY-521 | MPU-6050

## 7. モデリング

・ 状態フィードバックを用いた制御; ・状態方程式は同じものを使用; ・目標値に追従させるため新たなゲインGを追加

# 16 極指定


8. 結果

・６秒近く立たせる事が出来た。; ・重心を低くして実験すると不安定になった。; ・IMUの数値に多少ずれが生じてしまい、倒立するのに影響が 出てしまった。; ・機体の重量が重すぎたので、モータのギアが空回りしてし まった。; 台車の倒立; 重心位置を下げる; 再生リスト

# 9. まとめ

台車が大きく移動しないように倒立させることはできなかったが; 重心位置を変えることによる倒立の仕方の違いは調べる事が出来た。; GitHub Inverted_Pendulum-in-TAHU

# ご清聴ありがとうございました

現代制御理論入門; コロナ社

参考文献
・ Massimo Banzi著 Arduinoをはじめよう 第2版 O’REILLY 2012年3月15日

・2003年度-2009年度の九州工業高等専門学校電子制御工学科の講義資料
（ http://lab.cntl.kyutech.ac.jp/~nishida/pdf/09no13.pdf）

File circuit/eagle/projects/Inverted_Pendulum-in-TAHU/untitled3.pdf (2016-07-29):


2016/07/12 2:54 mirrored /home/taka/eagle-7.6.0/projects/Inverted_Pendulum-in-TAHU/untitled3.brd

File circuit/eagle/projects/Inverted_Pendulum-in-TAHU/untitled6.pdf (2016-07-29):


2016/07/14 12:27 f=2.00 mirrored /home/taka/eagle-7.6.0/projects/Inverted_Pendulum-in-TAHU/untitled6.brd

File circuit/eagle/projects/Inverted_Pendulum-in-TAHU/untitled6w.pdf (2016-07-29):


2016/07/24 18:24 /home/taka/eagle-7.6.0/projects/Inverted_Pendulum-in-TAHU/untitled6.sch (Sheet: 1/1)

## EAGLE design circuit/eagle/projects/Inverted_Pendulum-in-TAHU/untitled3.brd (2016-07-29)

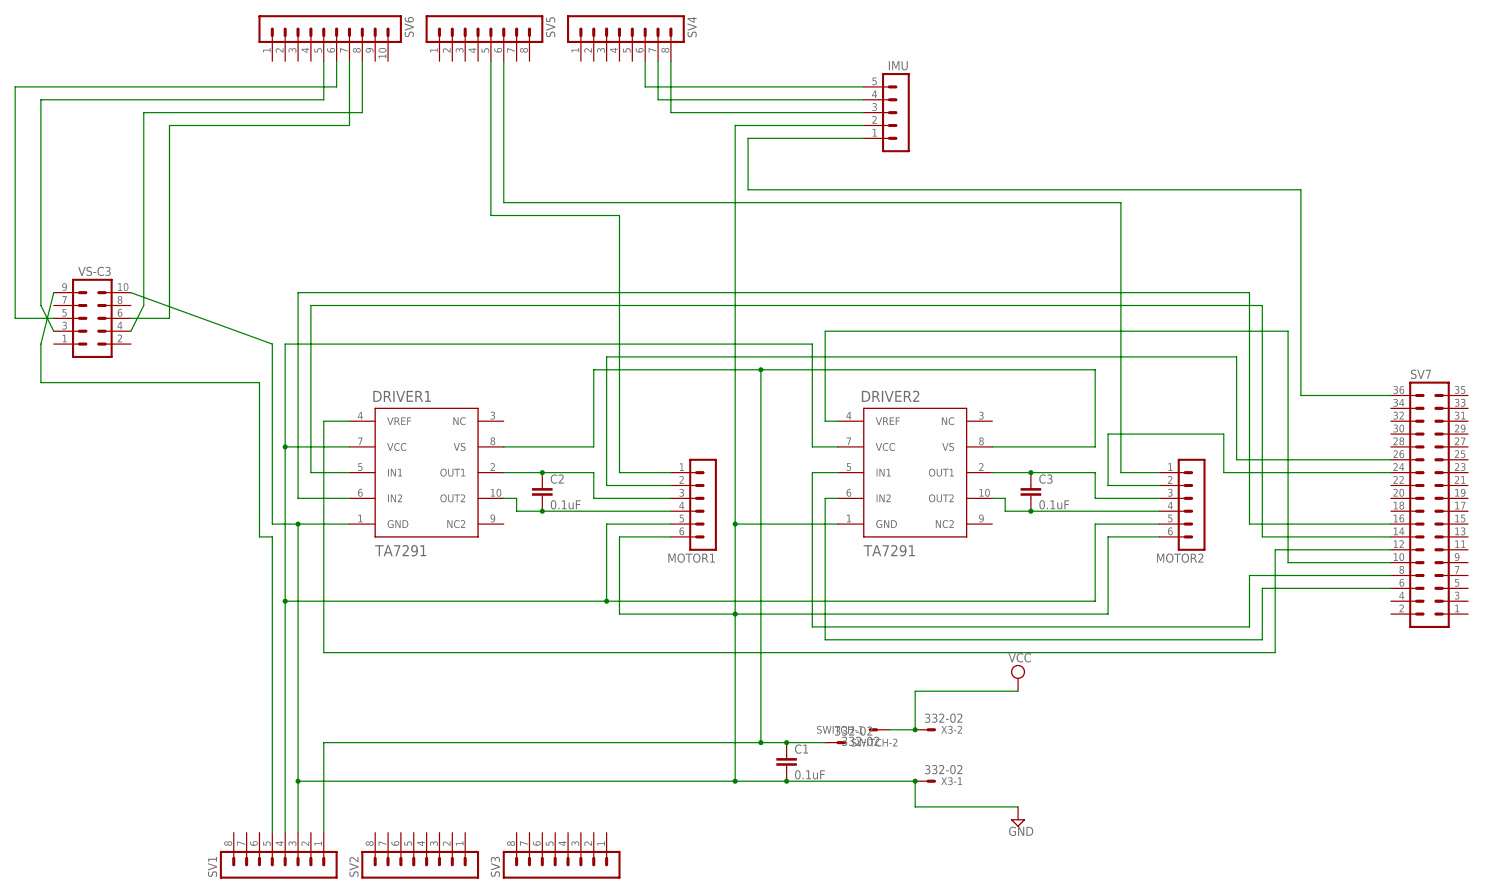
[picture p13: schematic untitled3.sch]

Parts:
C1, C2, C3: 0.1uF; C5B2.5
DRIVER1, DRIVER2: TA7291; HSIP10
IMU: MA05-1
MOTOR1, MOTOR2: MA06-1
SV1, SV2, SV3, SV4, SV5: MA08-1
SV6: MA10-1
SV7: MA18-2
SWITCH: 332-02
VS-C3: MA05-2
X3: 332-02

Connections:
ENCODER: IMU.5, SV4.6
GND: C1.2, DRIVER1.1 (GND), DRIVER2.1 (GND), IMU.2, MOTOR1.6, MOTOR2.6, SV1.3, VS-C3.10, X3.1
unnamed: C2.1, DRIVER1.2 (OUT1), MOTOR1.3
unnamed: C2.2, DRIVER1.10 (OUT2), MOTOR1.4
unnamed: C3.1, DRIVER2.2 (OUT1), MOTOR2.3
unnamed: C3.2, DRIVER2.10 (OUT2), MOTOR2.4
unnamed: IMU.1, SV7.36
unnamed: MOTOR2.1, SV5.6
unnamed: DRIVER1.7 (VCC), DRIVER2.7 (VCC), MOTOR1.5, MOTOR2.5, SV1.4
unnamed: IMU.3, SV4.8
unnamed: IMU.4, SV4.7
unnamed: C1.1, DRIVER1.8 (VS), DRIVER2.8 (VS), SV1.1, SWITCH.2
unnamed: DRIVER2.4 (VREF), SV7.10
unnamed: DRIVER1.5 (IN1), SV7.14
unnamed: MOTOR1.1, SV5.5
unnamed: MOTOR1.2, SV7.26
unnamed: MOTOR2.2, SV7.24
unnamed: DRIVER1.6 (IN2), SV7.16
unnamed: DRIVER2.5 (IN1), SV7.8
unnamed: DRIVER2.6 (IN2), SV7.6
unnamed: SV1.5, VS-C3.9
unnamed: SV6.6, VS-C3.5
unnamed: SV6.5, VS-C3.3
unnamed: SV6.8, VS-C3.4
unnamed: SV6.7, VS-C3.6
unnamed: DRIVER1.4 (VREF), SV7.12
VCC: SWITCH.1, X3.2

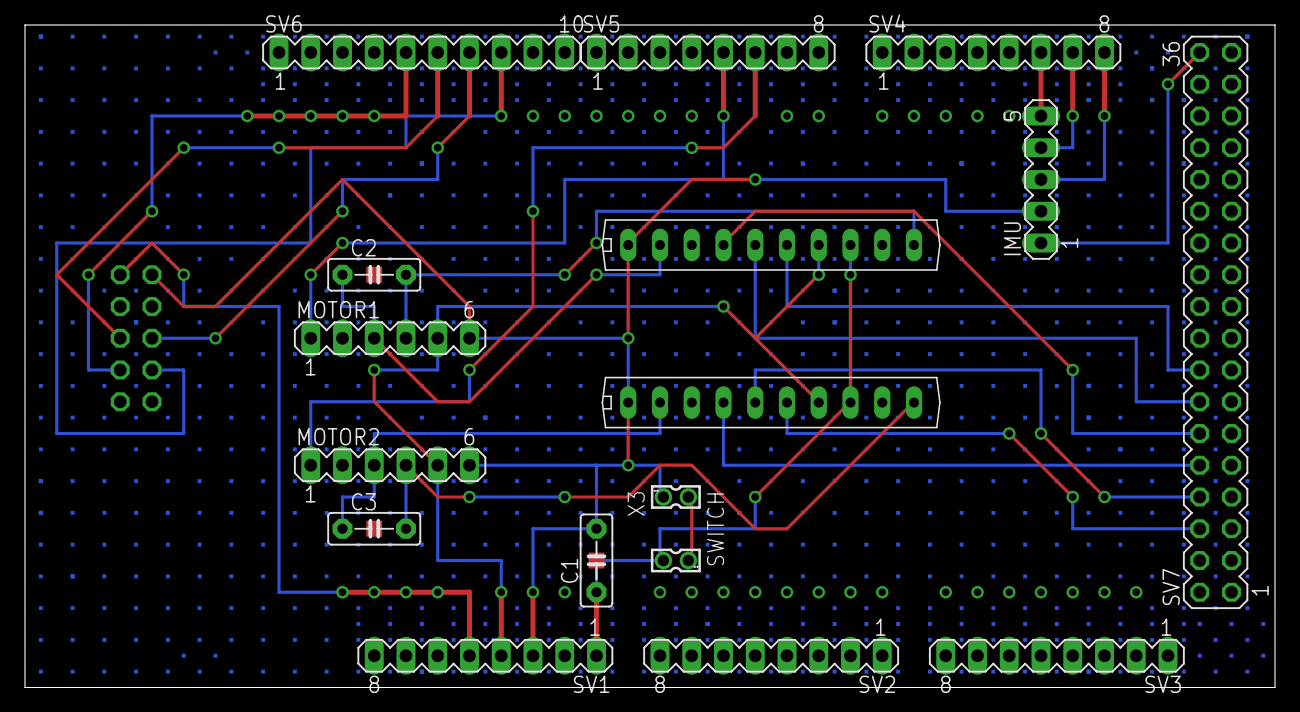
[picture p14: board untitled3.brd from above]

Board: 2 copper layers, 100.0 x 53.0 mm, 18 parts (1 on the bottom side), 27 nets.

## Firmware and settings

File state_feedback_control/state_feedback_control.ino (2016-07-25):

/* 状態フィードバック制御用 */
/* 作成開始日 2016.07.14    */

#include "PIN_NUMBER.h"
#include "FlexiTimer2.h"
#include "PS2X_lib.h" 
#include "MOTOR.h"
#include "I2Cdev.h"
#include "MPU6050_6Axis_MotionApps20.h"

#define USE_ENC_H  // 自作ライブラリを使用するか 未定義:使用しない Encoder.hを使用する場合はここをコメントにする。
#define SHOW_ENC_PULSE
#define USE_ATTACH_ENC //エンコーダに割り込みを使う ただし、12カウント
//#define NO_USE_ATTACH_ENC 
//#define SHOW_IMU

#ifdef USE_ENC_H
  #include "ENC.h"
#else
  #include "Encoder.h"
#endif

#if I2CDEV_IMPLEMENTATION == I2CDEV_ARDUINO_WIRE
  #include "Wire.h"
#endif

/* 状態フィードバックゲイン */
#define F1 59.7331
#define F2 18.5993
#define F3 -25.7582
#define F4 3.7104
#define G  -0.1391
#define KP -50
#define KI 0
#define KD 0
#define T 0.01 // サンプリングタイム 
#define PULSE_TO_METER 0.000491
/* MPU-6050 */
#define OUTPUT_READABLE_YAWPITCHROLL
#define INTERRUPT_PIN 19  // use pin 2 on Arduino Uno & most boards

bool blinkState = false;

PS2X ps2x;
MOTOR motor_right(MOTOR_RIGHT1,MOTOR_RIGHT2);
MOTOR motor_left(MOTOR_LEFT1,MOTOR_LEFT2);

#ifdef USE_ENC_H
  ENC enc_right(ENC_RIGHT_A,ENC_RIGHT_B,PULLUP);
  ENC enc_left(ENC_LEFT_A,ENC_LEFT_B,PULLUP);
#else
  Encoder enc_right(ENC_RIGHT_A,ENC_RIGHT_B);
  Encoder enc_left(ENC_LEFT_A,ENC_LEFT_B);
#endif

MPU6050 mpu;

int old_pulse = 0;
long positionLeft = -999;
long positionRight = -999;
int error = 0; 
byte vibrate = 0;
int right_pulse = 0;  // エンコーダのパルス
int left_pulse = 0;
int duty = 0;         // モータのデューティ比
float x = 0,dx = 0,x0 = 0,rx = 0.0;
float e = 0,ed = 0,theta = 0,dtheta = 0,theta0 = 0;
int ref_speed = 0.0;

// MPU control/status vars
bool dmpReady = false;  // set true if DMP init was successful
uint8_t mpuIntStatus;   // holds actual interrupt status byte from MPU
uint8_t devStatus;      // return status after each device operation (0 = success, !0 = error)
uint16_t packetSize;    // expected DMP packet size (default is 42 bytes)
uint16_t fifoCount;     // count of all bytes currently in FIFO
uint8_t fifoBuffer[64]; // FIFO storage buffer

// orientation/motion vars
Quaternion q;           // [w, x, y, z]         quaternion container
VectorFloat gravity;    // [x, y, z]            gravity vector
float ypr[3];           // [yaw, pitch, roll]   yaw/pitch/roll container and gravity vector

// packet structure for InvenSense teapot demo
uint8_t teapotPacket[14] = { '$', 0x02, 0,0, 0,0, 0,0, 0,0, 0x00, 0x00, '\r', '\n' };

void right_enc(void)
{
  enc_right.encode();
}

void left_enc(void)
{
  enc_left.encode();
}

void CONTROLER(void)
{
  ps2x.read_gamepad(false, vibrate);

  if(ps2x.Button(PSB_START)) //スタートボタン
    Serial.println("Start");
    
  if(ps2x.Button(PSB_SELECT)) //セレクトボタン
    Serial.println("Select");

  if(ps2x.Button(PSB_PAD_UP)) //上ボタン
    Serial.println("U");
     
  if(ps2x.Button(PSB_PAD_RIGHT)) //右ボタン 
    Serial.println("R"); 
  if(ps2x.Button(PSB_PAD_LEFT)) //左ボタン
    Serial.println("L"); 
  if(ps2x.Button(PSB_PAD_DOWN)) //下ボタン
    Serial.println("D"); 

  if(ps2x.Button(PSB_GREEN)) //三角ボタン
    Serial.println("G"); 
  if(ps2x.Button(PSB_RED)) //丸ボタン
    Serial.println("O"); 
  if(ps2x.Button(PSB_PINK)) //四角ボタン
    Serial.println("P"); 
  if(ps2x.Button(PSB_BLUE)) //エックスボタン
    Serial.println("X");

  if(ps2x.Button(PSB_L3))
    Serial.println("L3");
  if(ps2x.Button(PSB_R3))
    Serial.println("R3");
  if(ps2x.Button(PSB_L2))
    Serial.println("L2");
  if(ps2x.Button(PSB_R2))
    Serial.println("R2"); 
  if(ps2x.Button(PSB_R1))
    Serial.println("R1");

  if(ps2x.Button(PSB_L1)) // Ｌ１を押しながら、アナログスチックコントロール
  {
    Serial.print(ps2x.Analog(PSS_LY), DEC); 
    Serial.print(",");
    Serial.print(ps2x.Analog(PSS_LX), DEC); 
    Serial.print(",");
    Serial.print(ps2x.Analog(PSS_RY), DEC); 
    Serial.print(",");
    Serial.println(ps2x.Analog(PSS_RX), DEC); 
  } 

}

/* 状態フィードバック制御 */
void STATE_FEEDBACK_CONTROLL(void)
{
  #ifdef USE_ENC_H
  right_pulse = enc_right.get_pulses();
  left_pulse = enc_left.get_pulses();
  #endif
  
  enc_right.reset();
  enc_left.reset();
  
  x = (float)(left_pulse - right_pulse) / 2 * PULSE_TO_METER; 
  
  dx = (x - x0) / T;
  x0 = x;
  theta = 0.03+ypr[1];
  dtheta = ed;
  theta0 = theta;
   
  duty =( x * F1 + dx * F2 + theta * F3 + dtheta * F4 + rx * G ) * 255;
  //duty = ( KP * theta + KD * dtheta )*255;
  if(duty > 255) duty = 255;
  if(duty < -255) duty = -255;
  
  motor_right = -duty;
  motor_left = duty;
    
}

// ================================================================
// ===               INTERRUPT DETECTION ROUTINE                ===
// ================================================================

volatile bool mpuInterrupt = false;     // indicates whether MPU interrupt pin has gone high

void dmpDataReady() {
    mpuInterrupt = true;
}

void setup(void)
{
  // join I2C bus (I2Cdev library doesn't do this automatically)
  #if I2CDEV_IMPLEMENTATION == I2CDEV_ARDUINO_WIRE
      Wire.begin();
      Wire.setClock(400000); // 400kHz I2C clock. Comment this line if having compilation difficulties
  #elif I2CDEV_IMPLEMENTATION == I2CDEV_BUILTIN_FASTWIRE
      Fastwire::setup(400, true);
  #endif
    
  Serial.begin(115200);
  while (!Serial);

  error = ps2x.config_gamepad(CON_PIN1,CON_PIN2,CON_PIN3,CON_PIN4,true,true);
 
  if(error == 0){
    Serial.println("0 Found Controller, configured successful");
  }

  else if(error == 1)
    Serial.println("1 No controller found, check wiring, see readme.txt to enable debug. ");

  else if(error == 2)
    Serial.println("2 Controller found but not accepting commands. see readme.txt to enable debug. ");

  else if(error == 3)
    Serial.println("3 Controller refusing to enter Pressures mode, may not support it. ");

//Serial.print(ps2x.Analog(1), HEX);
   Serial.println(" PS-C2 Controller Found OK! "); //ＰＳ－２Ｃコントローラー 

  /* エンコーダの割り込み */
  #ifdef USE_ATTACH_ENC
    attachInterrupt(1,right_enc,RISING);
    attachInterrupt(1,right_enc,FALLING);
    attachInterrupt(0,left_enc,RISING);
    attachInterrupt(0,left_enc,FALLING);
  #endif
   
   FlexiTimer2::set(10,STATE_FEEDBACK_CONTROLL);
  //FlexiTimer2::set(10,CONTROLER);
   FlexiTimer2::start();

  // initialize device
   Serial.println(F("Initializing I2C devices..."));
   mpu.initialize();
   pinMode(INTERRUPT_PIN, INPUT);

    // verify connection
   Serial.println(F("Testing device connections..."));
   Serial.println(mpu.testConnection() ? F("MPU6050 connection successful") : F("MPU6050 connection failed"));

    // wait for ready// initialize device
   Serial.println(F("Initializing I2C devices..."));
   mpu.initialize();
   pinMode(INTERRUPT_PIN, INPUT);

    // verify connection
   Serial.println(F("Testing device connections..."));
   Serial.println(mpu.testConnection() ? F("MPU6050 connection successful") : F("MPU6050 connection failed"));

    // wait for ready
   Serial.println(F("\nSend any character to begin DMP programming and demo: "));
    

    // load and configure the DMP
   Serial.println(F("Initializing DMP..."));
   devStatus = mpu.dmpInitialize();

    // supply your own gyro offsets here, scaled for min sensitivity
   mpu.setXGyroOffset(220);
   mpu.setYGyroOffset(76);
   mpu.setZGyroOffset(-85);
   mpu.setZAccelOffset(1788); // 1688 factory default for my test chip

    // make sure it worked (returns 0 if so)
   if (devStatus == 0) {
       // turn on the DMP, now that it's ready
       Serial.println(F("Enabling DMP..."));
       mpu.setDMPEnabled(true);

        // enable Arduino interrupt detection
       Serial.println(F("Enabling interrupt detection (Arduino external interrupt 0)..."));
       attachInterrupt(digitalPinToInterrupt(INTERRUPT_PIN), dmpDataReady, RISING);
       mpuIntStatus = mpu.getIntStatus();

        // set our DMP Ready flag so the main loop() function knows it's okay to use it
       Serial.println(F("DMP ready! Waiting for first interrupt..."));
       dmpReady = true;

       // get expected DMP packet size for later comparison
       packetSize = mpu.dmpGetFIFOPacketSize();
   } else {
        // ERROR!
        // 1 = initial memory load failed
        // 2 = DMP configuration updates failed
        // (if it's going to break, usually the code will be 1)
       Serial.print(F("DMP Initialization failed (code "));
       Serial.print(devStatus);
       Serial.println(F(")"));
   }

    // configure LED for output
    Serial.println(F("\nSend any character to begin DMP programming and demo: "));
    

    // load and configure the DMP
    Serial.println(F("Initializing DMP..."));
    devStatus = mpu.dmpInitialize();

    // supply your own gyro offsets here, scaled for min sensitivity
    mpu.setXGyroOffset(220);
    mpu.setYGyroOffset(76);
    mpu.setZGyroOffset(-85);
    mpu.setZAccelOffset(1788); // 1688 factory default for my test chip

    // make sure it worked (returns 0 if so)
    if (devStatus == 0) {
        // turn on the DMP, now that it's ready
        Serial.println(F("Enabling DMP..."));
        mpu.setDMPEnabled(true);

        // enable Arduino interrupt detection
        Serial.println(F("Enabling interrupt detection (Arduino external interrupt 0)..."));
        attachInterrupt(digitalPinToInterrupt(INTERRUPT_PIN), dmpDataReady, RISING);
        mpuIntStatus = mpu.getIntStatus();

        // set our DMP Ready flag so the main loop() function knows it's okay to use it
        Serial.println(F("DMP ready! Waiting for first interrupt..."));
        dmpReady = true;

        // get expected DMP packet size for later comparison
        packetSize = mpu.dmpGetFIFOPacketSize();
    } else {
        // ERROR!
        // 1 = initial memory load failed
        // 2 = DMP configuration updates failed
        // (if it's going to break, usually the code will be 1)
        Serial.print(F("DMP Initialization failed (code "));
        Serial.print(devStatus);
        Serial.println(F(")"));
    }

}

void loop(void)
{ 
  #ifdef NO_USE_ATTACH_ENC
    enc_right.enc_count();
    enc_left.enc_count();
  #endif
  
  #ifndef USE_ENC_H
    right_pulse = enc_right.read(); 
    left_pulse = enc_left.read();
  #endif
  
  
  /* MPU-6050 */
  // if programming failed, don't try to do anything
    if (!dmpReady) return;

    // wait for MPU interrupt or extra packet(s) available
    while (!mpuInterrupt && fifoCount < packetSize) {
        // other program behavior stuff here
        // .
        // .
        // .
        // if you are really paranoid you can frequently test in between other
        // stuff to see if mpuInterrupt is true, and if so, "break;" from the
        // while() loop to immediately process the MPU data
        // .
        // .
        // .
    }

    // reset interrupt flag and get INT_STATUS byte
    mpuInterrupt = false;
    mpuIntStatus = mpu.getIntStatus();

    // get current FIFO count
    fifoCount = mpu.getFIFOCount();

    // check for overflow (this should never happen unless our code is too inefficient)
    if ((mpuIntStatus & 0x10) || fifoCount == 1024) {
        // reset so we can continue cleanly
        mpu.resetFIFO();
        Serial.println(F("FIFO overflow!"));

    // otherwise, check for DMP data ready interrupt (this should happen frequently)
    } else if (mpuIntStatus & 0x02) {
        // wait for correct available data length, should be a VERY short wait
        while (fifoCount < packetSize) fifoCount = mpu.getFIFOCount();

        // read a packet from FIFO
        mpu.getFIFOBytes(fifoBuffer, packetSize);
        
        // track FIFO count here in case there is > 1 packet available
        // (this lets us immediately read more without waiting for an interrupt)
        fifoCount -= packetSize;

        #ifdef OUTPUT_READABLE_YAWPITCHROLL
            // display Euler angles in degrees
            mpu.dmpGetQuaternion(&q, fifoBuffer);
            mpu.dmpGetGravity(&gravity, &q);
            mpu.dmpGetYawPitchRoll(ypr, &q, &gravity);
            #ifdef SHOW_IMU
              Serial.print("ypr\t");
              Serial.println(ypr[1] );;
            //Serial.println(duty);;
            #endif
        #endif

        // blink LED to indicate activity
        blinkState = !blinkState;
    }

  #ifdef SHOW_ENC_PULSE
    if(old_pulse != left_pulse)
     Serial.println(left_pulse);
     old_pulse = left_pulse;
  #endif
    
  #ifndef USE_ENC_H
    delay(1);
  #endif
  
}

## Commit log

2016-07-04 ライブラリの作成
2016-07-04 samples内の整理＆説明追加
2016-07-07 add circuit
    [Seeed-OPL-for-customer-20151021.xlsx, untitled.brd, untitled.sch]
2016-07-07 Update circuit
    [untitled.brd, untitled.sch]
2016-07-29 add 回路の完成形＆スライド
    [untitled2.brd, untitled2.sch, untitled3.brd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]
